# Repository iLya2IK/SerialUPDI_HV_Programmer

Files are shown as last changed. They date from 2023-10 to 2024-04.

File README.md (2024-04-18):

# SerialUPDI_HV_Programmer

Простой программатор UPDI с функцией запуска протокола UPDI высоковольтным импульсом 12V. Последовательность сигналов для такого программирования приведена в разделе любого даташита к avr. Например:
[33.3.2.2 UPDI Enable with 12V Override of RESET pin](https://ww1.microchip.com/downloads/en/DeviceDoc/40001912A.pdf)

Инициализация протокола UPDI за счет подачи импульса высокого напряжения (12V) на пин UPDI/RESET предназначена для разблокировки устройства (в основном, типа Attiny), для которого данный пин был ранее запрограммирован на ввод-вывод и более не реагирует на программаторы другого типа (без импульса высокого напряжения).

Устройство разработано на основе схемы [SerialUPDI HV Programmer based on CH340E and MT360](https://github.com/wagiminator/AVR-Programmer/blob/master/SerialUPDI_HV_Programmer). Основные отличия:
1. Используется понижающий преобразователь напряжения NCP1529A для снижения напряжения от 5 В до 3.3 В
2. Вместо переключателя флажкового типа используется простая перемычка
3. Разъем USB поверхностного монтажа переделан в разъем типа JST XH2.54
4. В целях упрощения ручной пайки используются более крупные SMD компоненты форм-фактора 1206 для емкостей и 0805 для резисторов

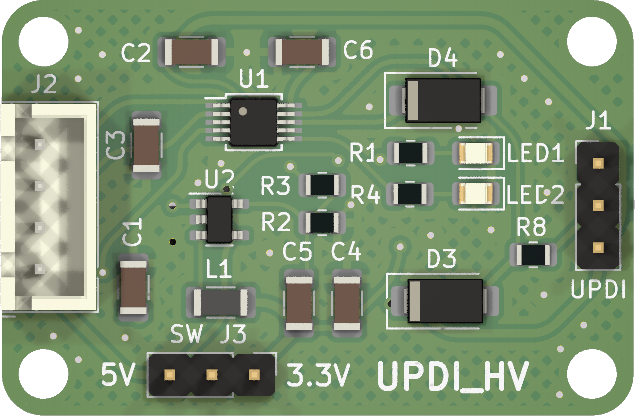
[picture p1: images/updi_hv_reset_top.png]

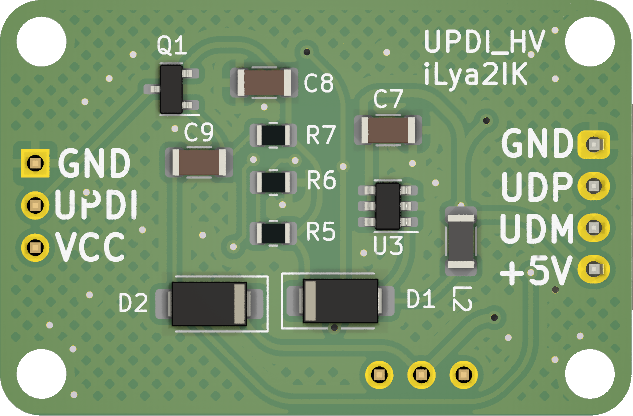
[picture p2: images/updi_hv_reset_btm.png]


Устройство собрано и протестировано. Для программирования использовал утилиту [Pure-C utility for programming AVR devices with UPDI interface using a standard TTL serial port](https://github.com/Polarisru/updiprog). Удалось записать hex файл, выставить/сбросить фьюзы с заблокированным пином UPDI.

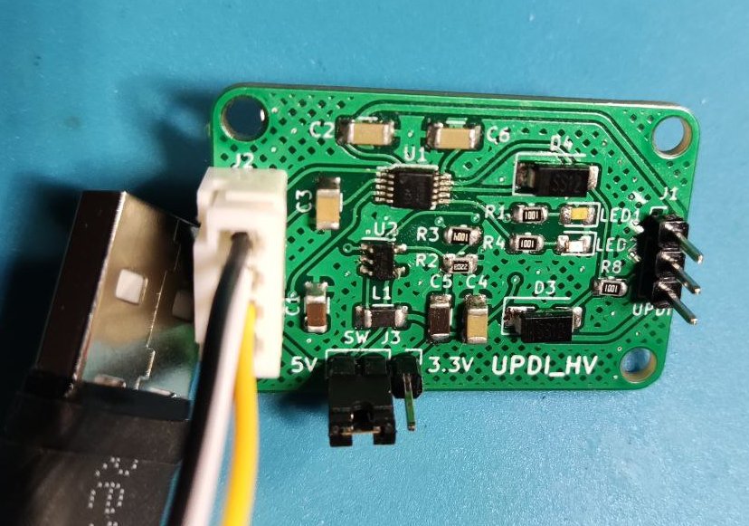
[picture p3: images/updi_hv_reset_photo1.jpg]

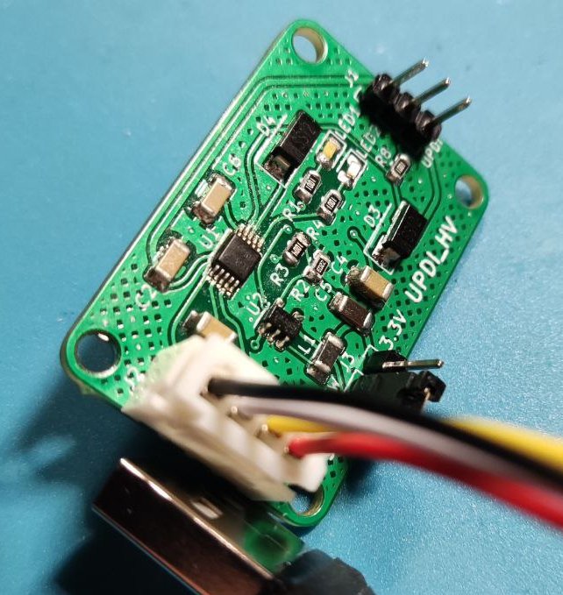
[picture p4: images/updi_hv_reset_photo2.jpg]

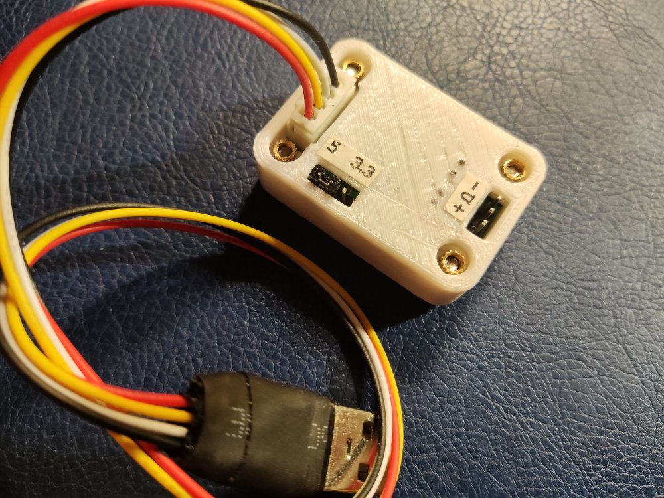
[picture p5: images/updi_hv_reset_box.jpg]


# References and copyrights
* [ATtiny214/414/814. Datasheet Preliminary](https://ww1.microchip.com/downloads/en/DeviceDoc/40001912A.pdf)
* [SerialUPDI HV Programmer based on CH340E and MT360](https://github.com/wagiminator/AVR-Programmer/blob/master/SerialUPDI_HV_Programmer)
* [Pure-C utility for programming AVR devices with UPDI interface using a standard TTL serial port](https://github.com/iLya2IK/updiprog)
* Copyright (c) 2023, Ilya Medvedkov

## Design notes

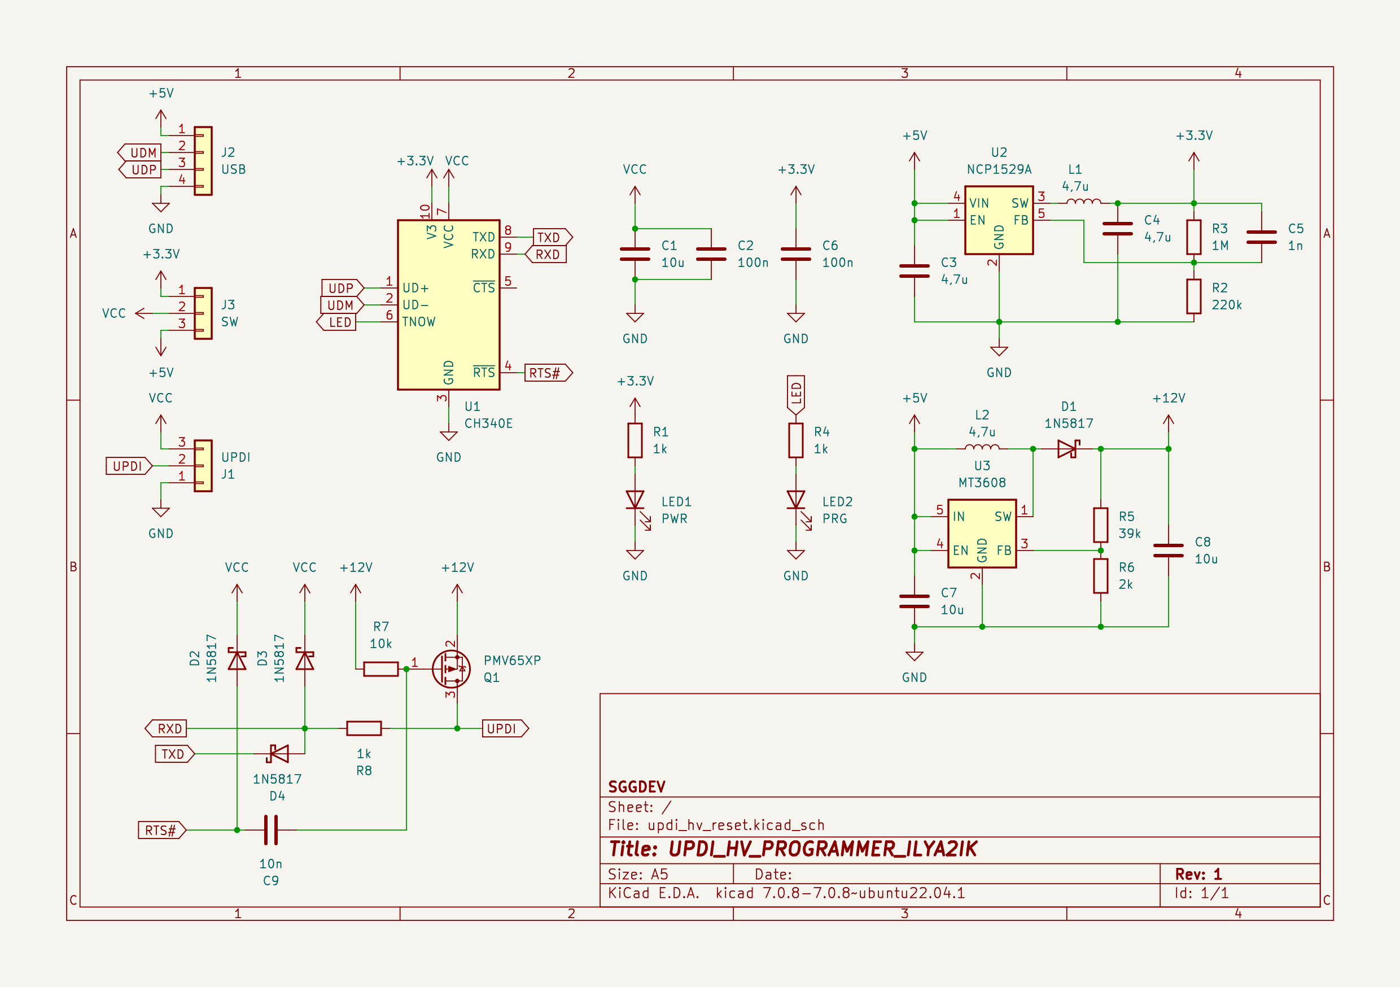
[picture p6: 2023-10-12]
images/updi_hv_reset_schematic.png

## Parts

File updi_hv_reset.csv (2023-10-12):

# | Reference | Qty | Value | Footprint | DNP
1 | C1, C7, C8 | 3 | 10u | Capacitor_SMD:C_1206_3216Metric
2 | C2, C6 | 2 | 100n | Capacitor_SMD:C_1206_3216Metric
3 | C3, C4 | 2 | 4,7u | Capacitor_SMD:C_1206_3216Metric
4 | C5 | 1 | 1n | Capacitor_SMD:C_1206_3216Metric
5 | C9 | 1 | 10n | Capacitor_SMD:C_1206_3216Metric
6 | D1, D2, D3, D4 | 4 | 1N5817 | Diode_SMD:D_SMA
7 | J1 | 1 | UPDI | Connector_PinHeader_2.54mm:PinHeader_1x03_P2.54mm_Vertical
8 | J2 | 1 | USB | Connector_JST:JST_XH_B4B-XH-A_1x04_P2.50mm_Vertical
9 | J3 | 1 | SW | Connector_PinHeader_2.54mm:PinHeader_1x03_P2.54mm_Vertical
10 | L1, L2 | 2 | 4,7u | Inductor_SMD:L_1206_3216Metric
11 | LED1 | 1 | PWR | LED_SMD:LED_0805_2012Metric
12 | LED2 | 1 | PRG | LED_SMD:LED_0805_2012Metric
13 | Q1 | 1 | PMV65XP | Package_TO_SOT_SMD:SOT-23
14 | R1, R4, R8 | 3 | 1k | Resistor_SMD:R_0805_2012Metric
15 | R2 | 1 | 220k | Resistor_SMD:R_0805_2012Metric
16 | R3 | 1 | 1M | Resistor_SMD:R_0805_2012Metric
17 | R5 | 1 | 39k | Resistor_SMD:R_0805_2012Metric
18 | R6 | 1 | 2k | Resistor_SMD:R_0805_2012Metric
19 | R7 | 1 | 10k | Resistor_SMD:R_0805_2012Metric
20 | U1 | 1 | CH340E | Package_SO:MSOP-10_3x3mm_P0.5mm
21 | U2 | 1 | NCP1529A | Package_TO_SOT_SMD:SOT-23-5
22 | U3 | 1 | MT3608 | Package_TO_SOT_SMD:SOT-23-6

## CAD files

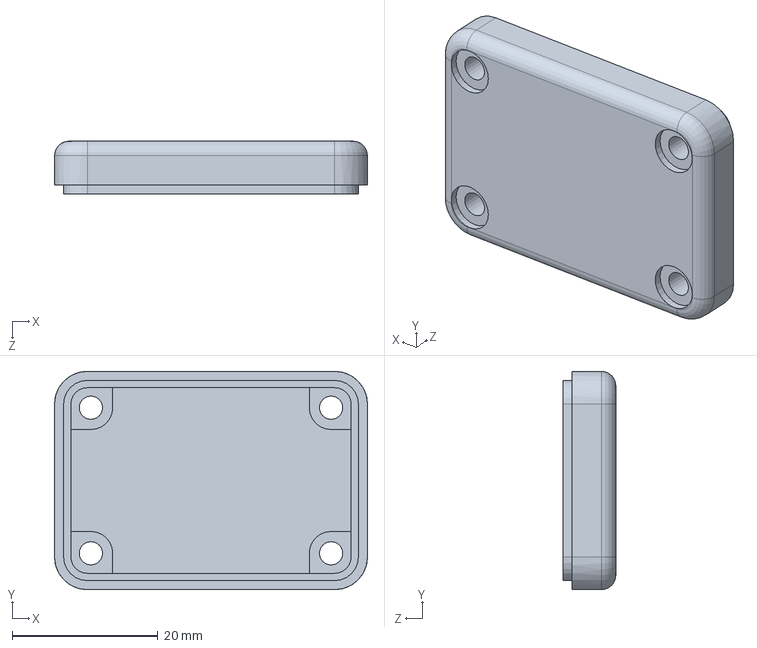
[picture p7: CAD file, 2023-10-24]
box/updi_box_bottom.SLDPRT
43.0 x 30.0 x 7.25 mm

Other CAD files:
box/updi_box_top.SLDPRT
box/updi_box_bottom.STL
box/updi_box_top.STL

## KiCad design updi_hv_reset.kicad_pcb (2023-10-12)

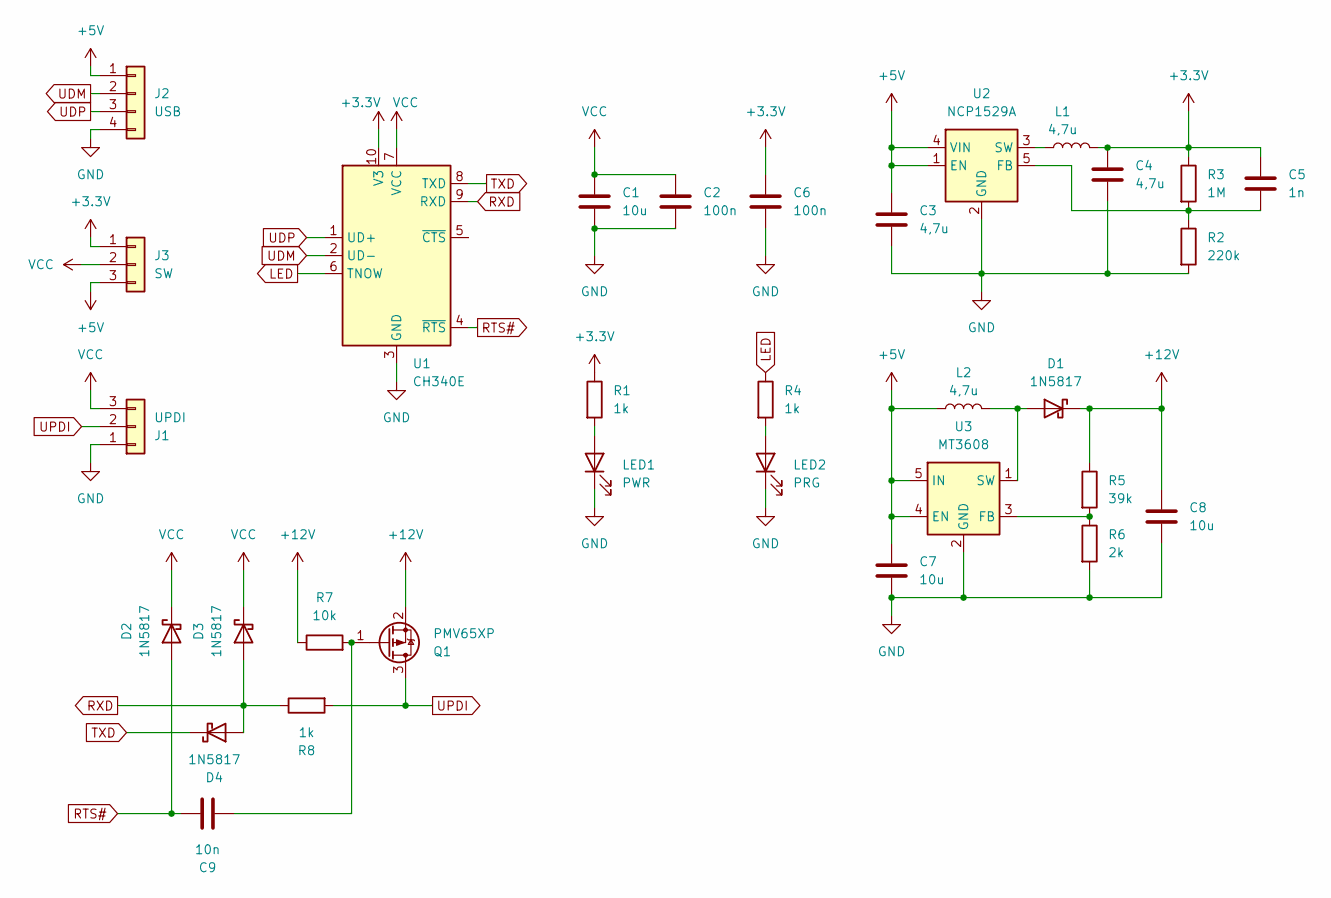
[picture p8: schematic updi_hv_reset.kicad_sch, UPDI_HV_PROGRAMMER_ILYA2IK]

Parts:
C1, C7, C8: 10u; C_1206_3216Metric
C2, C6: 100n; C_1206_3216Metric
C3, C4: 4,7u; C_1206_3216Metric
C5: 1n; C_1206_3216Metric
C9: 10n; C_1206_3216Metric
D1, D2, D3, D4: 1N5817; D_SMA
J1: UPDI; PinHeader_1x03_P2.54mm_Vertical
J2: USB; JST_XH_B4B-XH-A_1x04_P2.50mm_Vertical
J3: SW; PinHeader_1x03_P2.54mm_Vertical
L1, L2: 4,7u; L_1206_3216Metric
LED1: PWR; LED_0805_2012Metric
LED2: PRG; LED_0805_2012Metric
Q1: PMV65XP; SOT-23
R1, R4, R8: 1k; R_0805_2012Metric
R2: 220k; R_0805_2012Metric
R3: 1M; R_0805_2012Metric
R5: 39k; R_0805_2012Metric
R6: 2k; R_0805_2012Metric
R7: 10k; R_0805_2012Metric
U1: CH340E; MSOP-10_3x3mm_P0.5mm
U2: NCP1529A; SOT-23-5
U3: MT3608; SOT-23-6

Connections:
+3.3V: C4.1, C5.1, C6.1, J3.1, L1.2, R1.1, R3.1, U1.10 (V3)
+5V: C3.1, C7.1, J2.1, J3.3, L2.1, U2.1 (EN), U2.4 (VIN), U3.4 (EN), U3.5 (IN)
+12V: C8.1, D1.1 (K), Q1.2 (S), R5.1, R7.1
GND: C1.2, C2.2, C3.2, C4.2, C6.2, C7.2, C8.2, J1.1, J2.4, LED1.1 (K), LED2.1 (K), R2.2, R6.2, U1.3 (GND), U2.2 (GND), U3.2 (GND)
LED: R4.1, U1.6 (TNOW)
unnamed: D1.2 (A), L2.2, U3.1 (SW)
unnamed: LED1.2 (A), R1.2
unnamed: LED2.2 (A), R4.2
unnamed: C9.2, Q1.1 (G), R7.2
unnamed: C5.2, R2.1, R3.2, U2.5 (FB)
unnamed: L1.1, U2.3 (SW)
unnamed: R5.2, R6.1, U3.3 (FB)
RTS#: C9.1, D2.2 (A), U1.4 (~RTS)
RXD: D3.2 (A), D4.2 (A), R8.1, U1.9 (RXD)
TXD: D4.1 (K), U1.8 (TXD)
UDM: J2.2, U1.2 (UD-)
UDP: J2.3, U1.1 (UD+)
UPDI: J1.2, Q1.3 (D), R8.2
VCC: C1.1, C2.1, D2.1 (K), D3.1 (K), J1.3, J3.2, U1.7 (VCC)

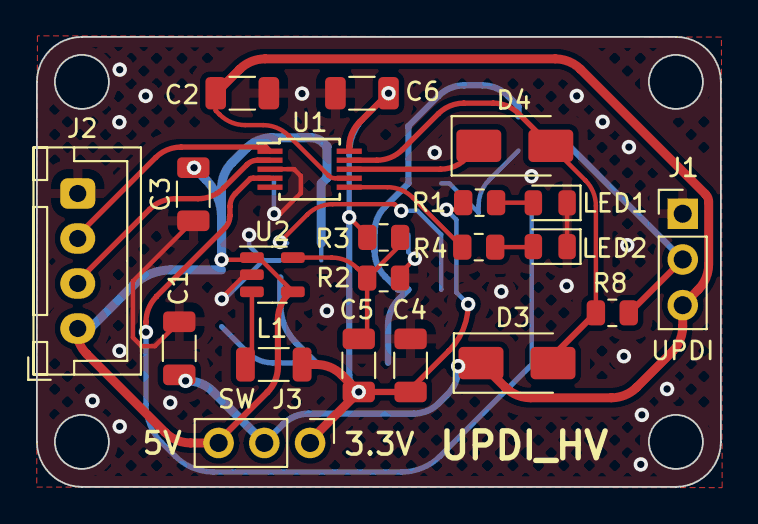
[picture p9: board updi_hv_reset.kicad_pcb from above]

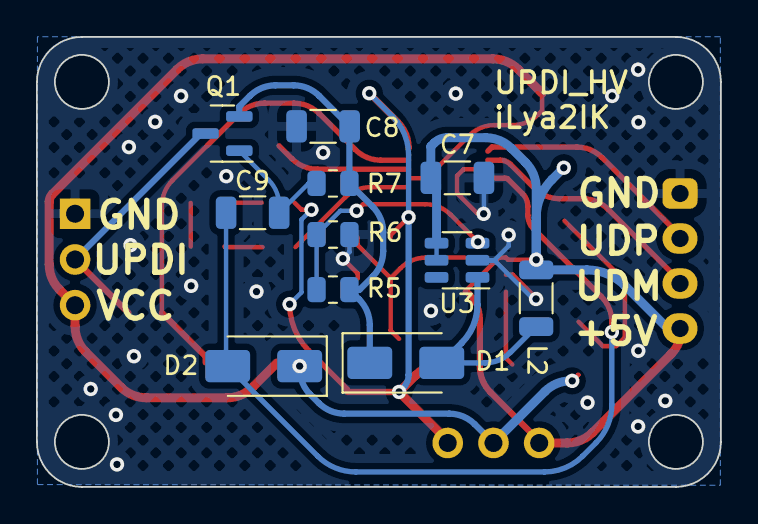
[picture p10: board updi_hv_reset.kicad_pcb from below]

Board: 2 copper layers, 38.0 x 25.0 mm, 32 parts (11 on the bottom side), 19 nets.

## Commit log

2023-10-12 README and pics added
    [updi_hv_reset.csv, updi_hv_reset.kicad_pcb, updi_hv_reset.kicad_sch]
2023-10-12 schematic pic added
2023-10-24 box design files added
    [updi_box_bottom.SLDPRT, updi_box_bottom.STL, updi_box_top.SLDPRT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]
